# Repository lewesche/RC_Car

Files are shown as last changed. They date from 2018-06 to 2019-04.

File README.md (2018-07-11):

# RC_Car

Building an Arduino powered RC car. Hoping to eventually turn this into more than an RC car at some point (vision? autonomy? camera with gimbal?). Mostly just trying to keep track of files for myself as of now, but feel free to use any of this. CAD is done in Solidworks/Onshape (free option) and most parts are designed to be 3D printed. Code could be a useful reference for PWM control/radio communication.

## Hardware
##### Arduino Uno (2) 
https://store.arduino.cc/usa/arduino-uno-rev3
Note: One Uno used to send the joystick signal, the other is used integrated into the car to receive the signal. A Mini could be used instead to send the signal. 
##### TB6612 H-Bridge Controller (1)
https://learn.adafruit.com/adafruit-tb6612-h-bridge-dc-stepper-motor-driver-breakout?view=all
Note: One channel is set to output a constant ~5.5v for the servos, the other channel is activley controlled to run the driveshaft.
##### NRF24L01 Radio (2)
https://www.amazon.com/MakerFocus-NRF24L01-Transceiver-Antistatic-Compatible/dp/B01IK78PQA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
##### NRF24L01 5v Adapter Socket (1)
https://www.amazon.com/gp/product/B00NJCB7FS/ref=oh_aui_detailpage_o02_s00?ie=UTF8&psc=1
Note: Only one of these is used on the sender side. The idea is to hopefully imporve the range by working around some power issues associated with using the Uno's 3.3v onboard power. 
##### Joystick (1)
https://www.amazon.com/WGCD-Joystick-Breakout-Controller-Arduino/dp/B01N59MK0U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
Note: These joysticks aren't very sensitive. I'll probably look for better ones eventually.
##### 12V 200rpm DC motor (1)
https://www.amazon.com/Greartisan-Electric-Reduction-Eccentric-Diameter/dp/B072R5QSRG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
Note: Could use a higher RPM motor, this is just what I had.
##### 180 deg Servo (2)
https://www.amazon.com/Adafruit-Micro-Servo-Torque-ADA1143/dp/B01BMRDXK8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
##### Bevel Gears
https://www.amazon.com/gp/product/B004N62ZGE/ref=oh_aui_detailpage_o05_s00?ie=UTF8&psc=1

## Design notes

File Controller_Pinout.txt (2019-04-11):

Rover Arduino Pinout

3.3v - NRF
5v - Joystick
GND - NRF, Joystick

0 -
1 - 
2 - 
3 - 
4 - 
5 - 
6 - 
7 - NRF CE
8 - NRF CSN
9 - 
10 - 
11 - NRF MOS
12 - NRF MSC
13 - NRF SCK

A0 - VRY
A1 - VRX
A2 - 
A3 - 
A4 - 
A5 -

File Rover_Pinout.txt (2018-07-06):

Rover Arduino Pinout

3.3v - NRF
5v - Tb6612
GND - NRF, TB6612
vin - Vm

0 -
1 - 
2 - Servo1, Servo2
3 - AIN1
4 - AIN2
5 - PWMA
6 - IN1B
7 - NRF CE
8 - NRF CSN
9 - BIN2
10 - PWMB
11 - NRF MOS
12 - NRF MSC
13 - NRF SCK

A0 - Voltage/3 read
A1 - 
A2 - 
A3 - 
A4 - 
A5 - Low voltage indicator LED

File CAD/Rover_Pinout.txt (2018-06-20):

Rover Arduino Pinout

3.3v - NRF
5v - Servos
GND - NRF, Servos, DRV
vin - DRV vm

1 - 
2 - Servo1
3 - Servo2
4 - 
5 - DRV IN1
6 - DRV IN2
7 - NRF CE
8 - 
9 - 
10 - NRF CSN 
11 - NRF MOS
12 - NRF MSC
13 - NRF SCK

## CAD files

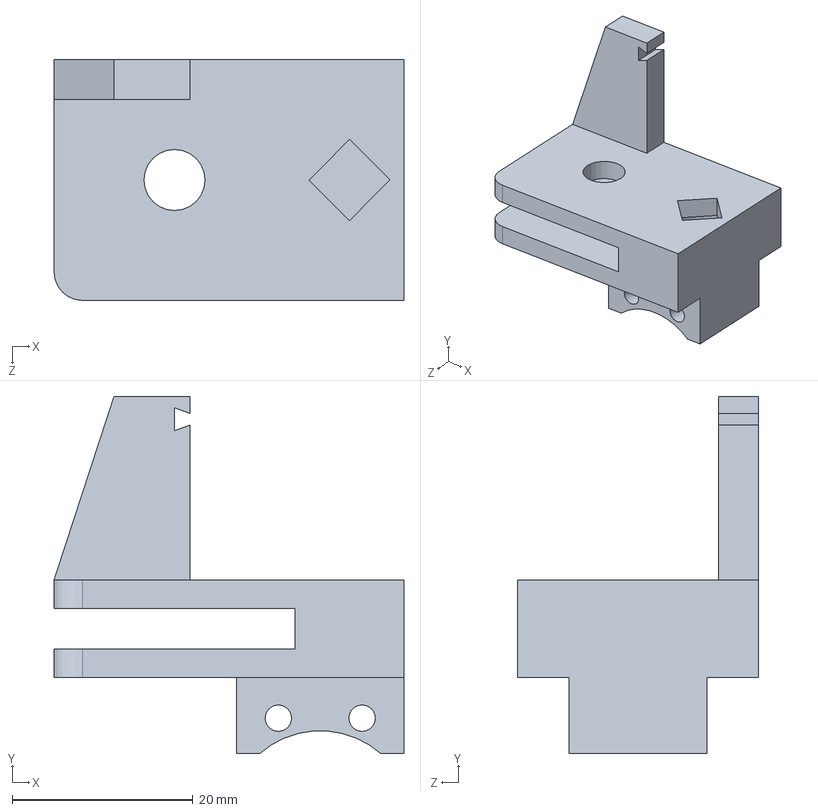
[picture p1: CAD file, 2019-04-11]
CAD/Solidworks Parts/Steering_Mount_Left.SLDPRT
38.7 x 39.6 x 26.7 mm

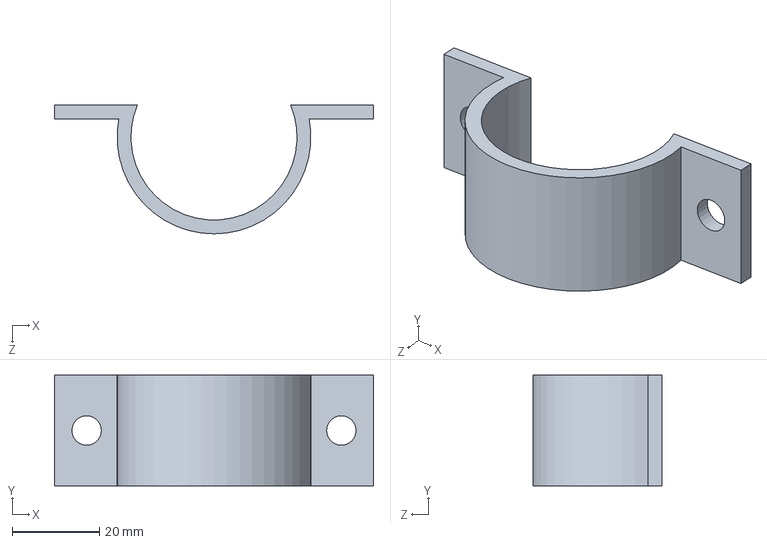
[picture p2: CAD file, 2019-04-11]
CAD/Solidworks Parts/Motor_Mount_Bottom.SLDPRT
73.2 x 25.4 x 29.5 mm

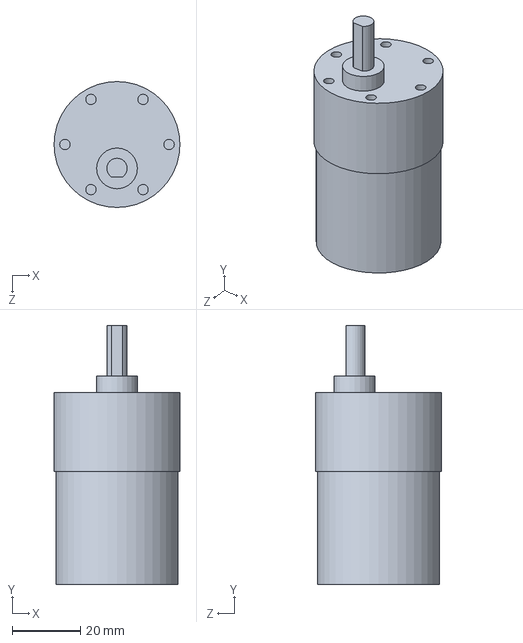
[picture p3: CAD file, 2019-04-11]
CAD/Solidworks Parts/Motor.SLDPRT
36.8 x 75.8 x 36.8 mm

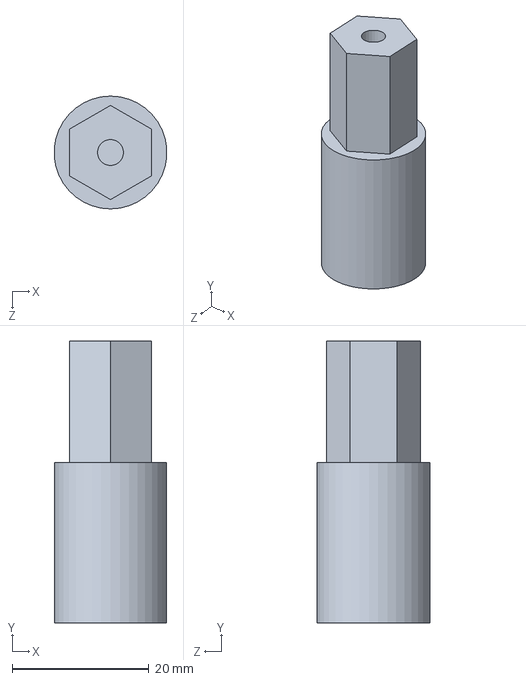
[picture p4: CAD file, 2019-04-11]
CAD/Solidworks Parts/Front_Bearing.SLDPRT
16.5 x 41.3 x 16.5 mm

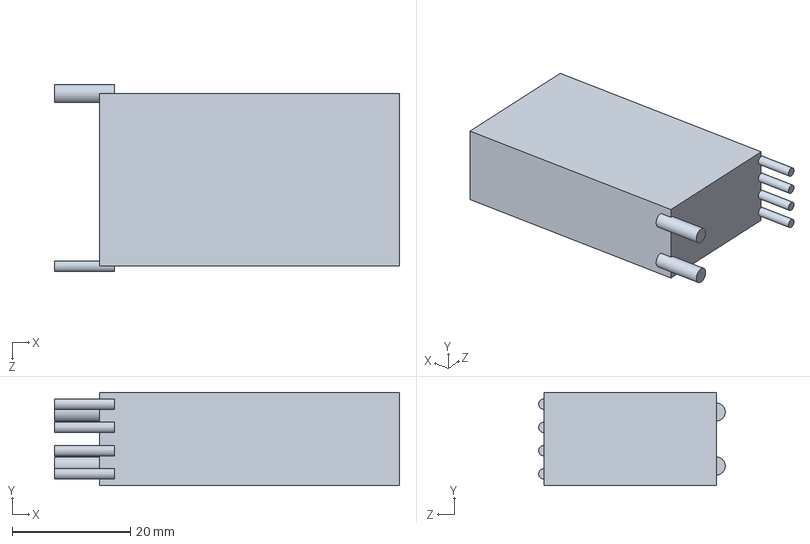
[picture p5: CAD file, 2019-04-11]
CAD/Solidworks Parts/LiPo_450.SLDPRT
58.4 x 15.7 x 31.6 mm

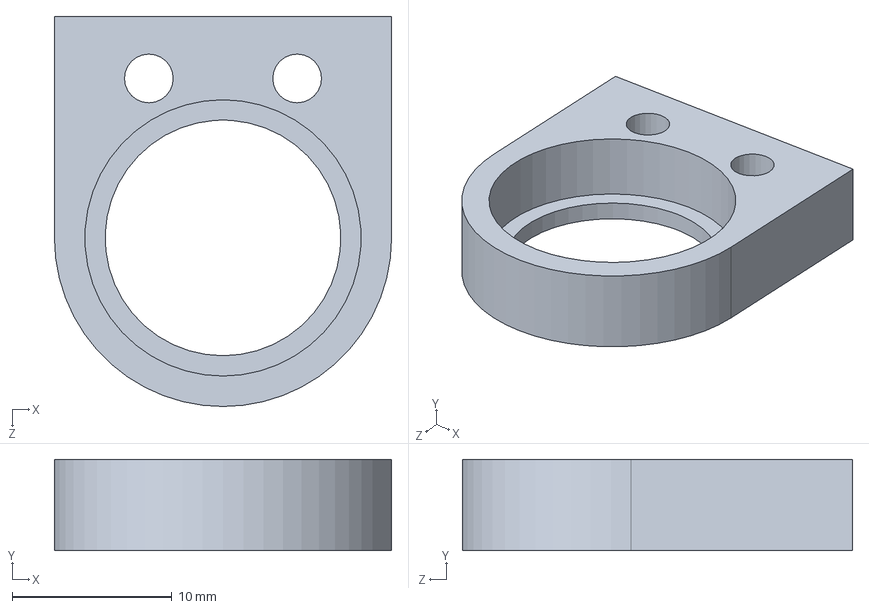
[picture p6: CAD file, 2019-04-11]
CAD/Solidworks Parts/Front_Mount.SLDPRT
21.1 x 5.72 x 24.4 mm

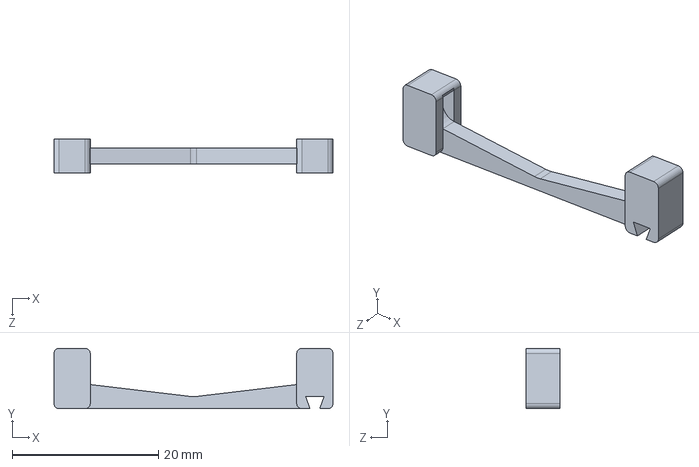
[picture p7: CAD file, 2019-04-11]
CAD/Solidworks Parts/Servo_Attachment.SLDPRT
38.1 x 8.26 x 4.70 mm

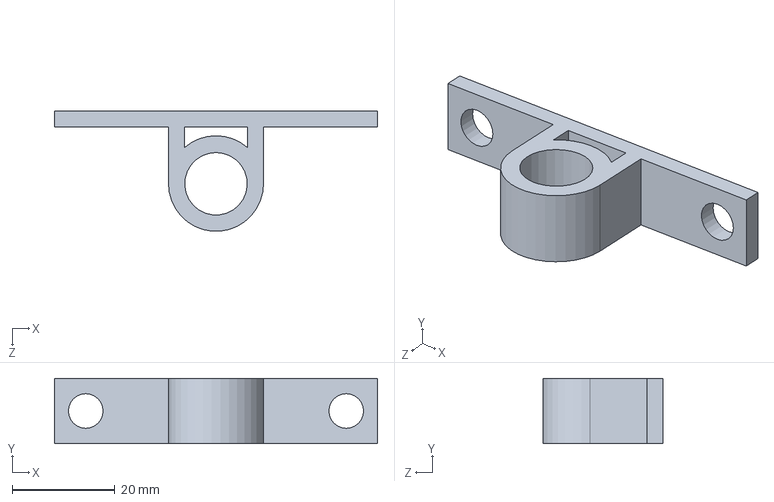
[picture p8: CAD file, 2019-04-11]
CAD/Solidworks Parts/Driveshaft_Mount.SLDPRT
63.0 x 12.7 x 23.5 mm

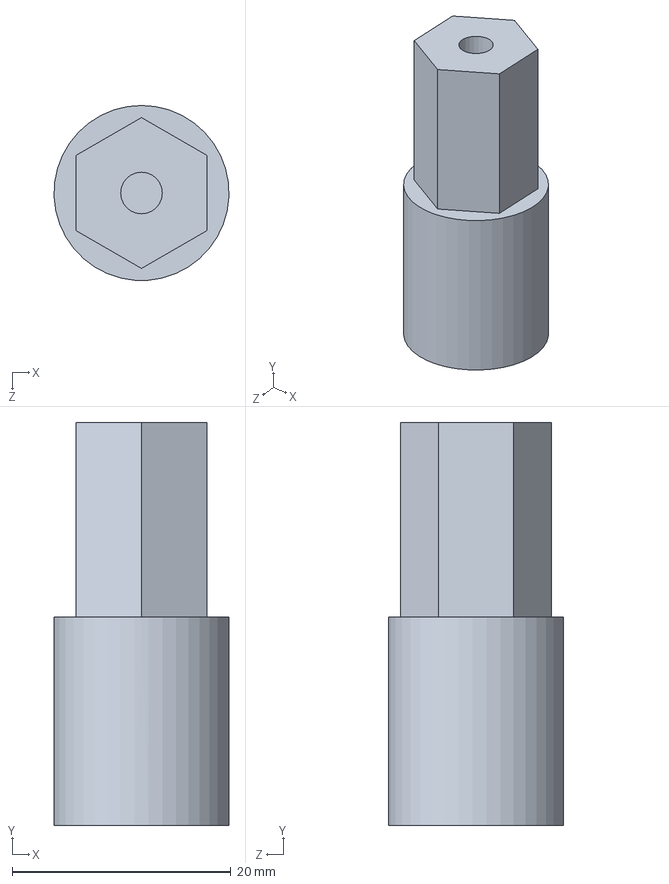
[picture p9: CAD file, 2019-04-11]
CAD/Solidworks Parts/Rear_Axle_Rod.SLDPRT
16.0 x 36.8 x 16.0 mm

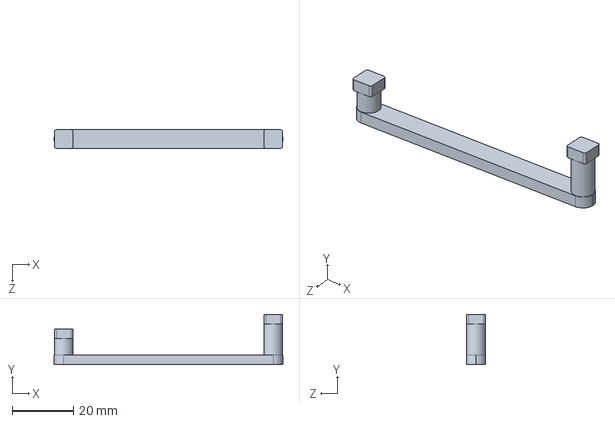
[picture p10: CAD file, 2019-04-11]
CAD/Solidworks Parts/Steering_linkage.SLDPRT
74.9 x 16.5 x 6.35 mm

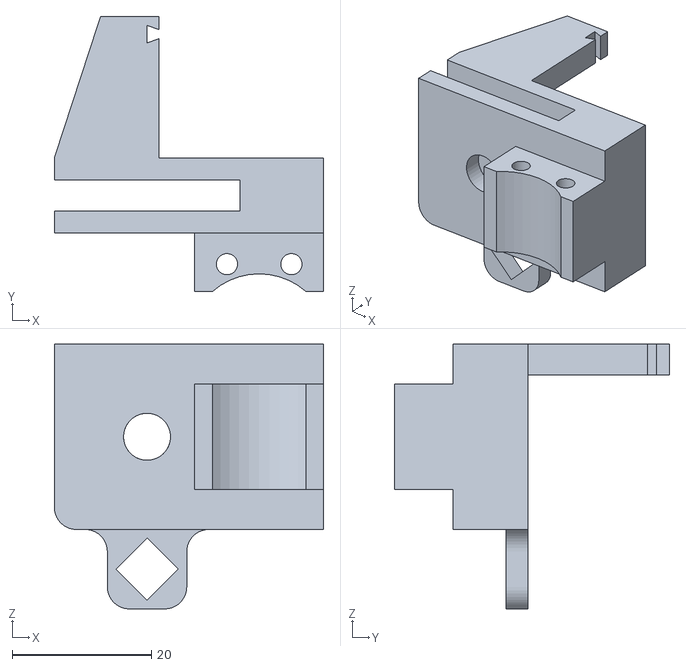
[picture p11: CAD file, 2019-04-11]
CAD/Solidworks Parts/Steering_Mount_Right_test2.STL
38.7 x 39.6 x 38.1

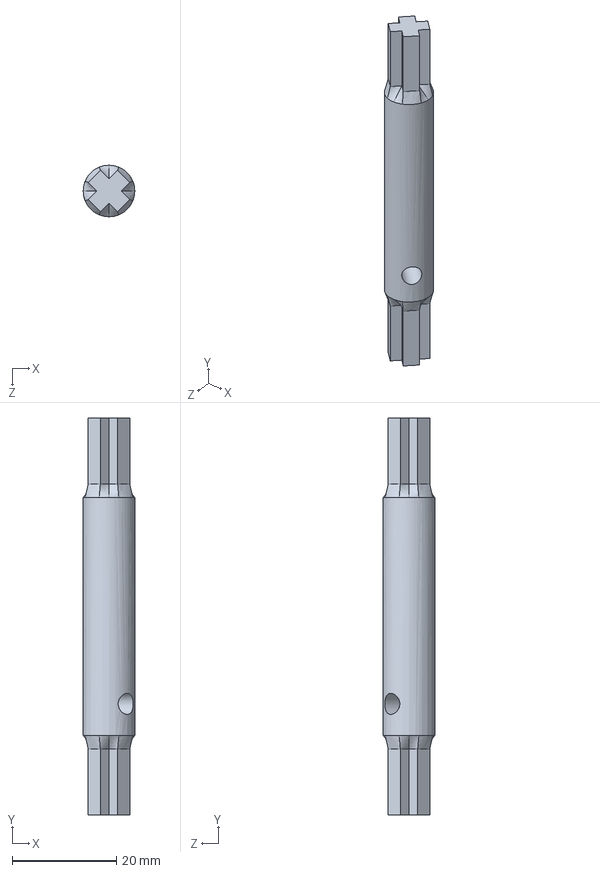
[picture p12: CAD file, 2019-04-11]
CAD/Solidworks Parts/Rear_Axle_cross.SLDPRT
9.91 x 76.2 x 9.91 mm

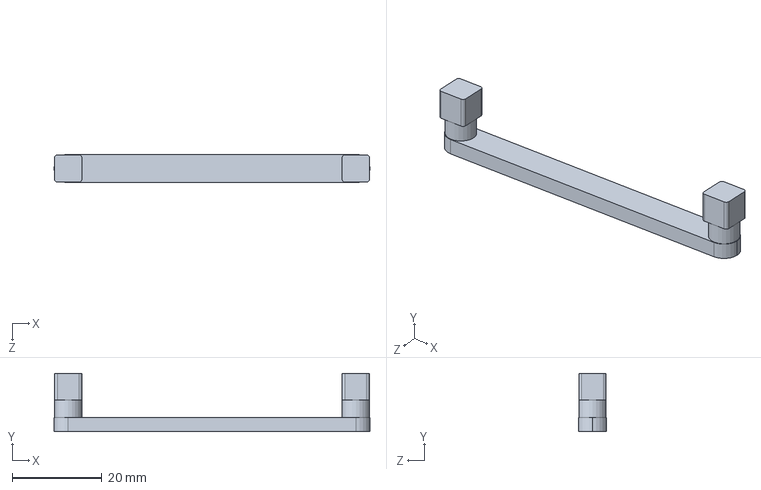
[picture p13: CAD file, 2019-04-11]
CAD/Solidworks Parts/Steering_Rack.SLDPRT
70.5 x 13.0 x 6.35 mm

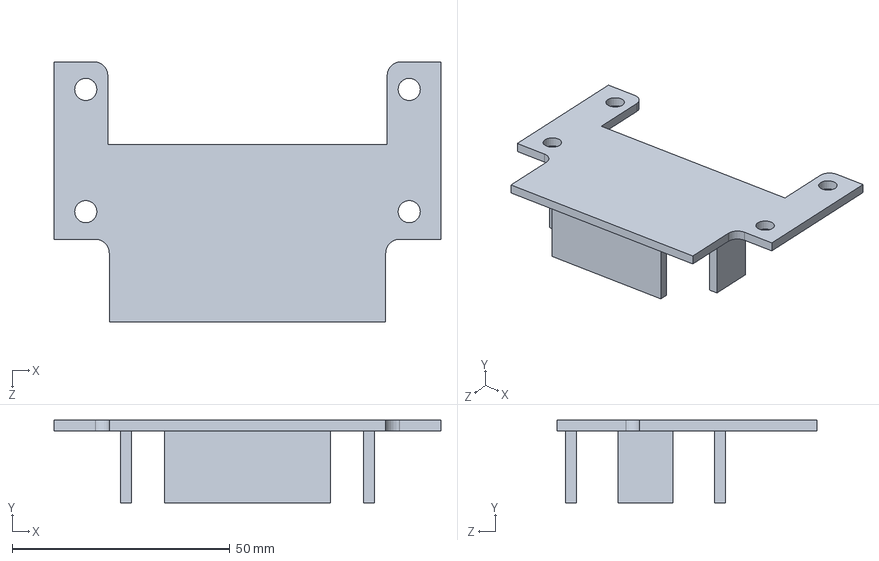
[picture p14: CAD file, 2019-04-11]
CAD/Solidworks Parts/LiPo_Mount.SLDPRT
88.9 x 19.1 x 59.8 mm

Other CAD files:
CAD/Solidworks Parts/Rear_Axle_Mount.SLDPRT
CAD/Solidworks Parts/MG90S_Servo.SLDPRT
CAD/Solidworks Parts/Steering_Mount.SLDPRT
CAD/Solidworks Parts/Arduino UNO.SLDPRT
CAD/Solidworks Parts/Bevel_Gear_2.SLDPRT
CAD/Solidworks Parts/Bevel_Gear_3.SLDPRT
CAD/Solidworks Parts/Driveshaft.SLDPRT
CAD/Solidworks Parts/Front_Wheel.SLDPRT
CAD/Solidworks Parts/Gear_Test_Fit.SLDPRT
CAD/Solidworks Parts/Motor_Mount_Top.SLDPRT
CAD/Solidworks Parts/Motor_Rod.SLDPRT
CAD/Solidworks Parts/Plate.SLDPRT
CAD/Solidworks Parts/RC_Plate.DXF
CAD/Solidworks Parts/Rear_Wheel.SLDPRT
CAD/Solidworks Parts/Servo_Attachment_2.SLDPRT
CAD/Solidworks Parts/Steering_Mount_Left.STL
CAD/Solidworks Parts/Steering_Mount_Right.SLDPRT
CAD/Solidworks Parts/Test_Fit_4.SLDPRT

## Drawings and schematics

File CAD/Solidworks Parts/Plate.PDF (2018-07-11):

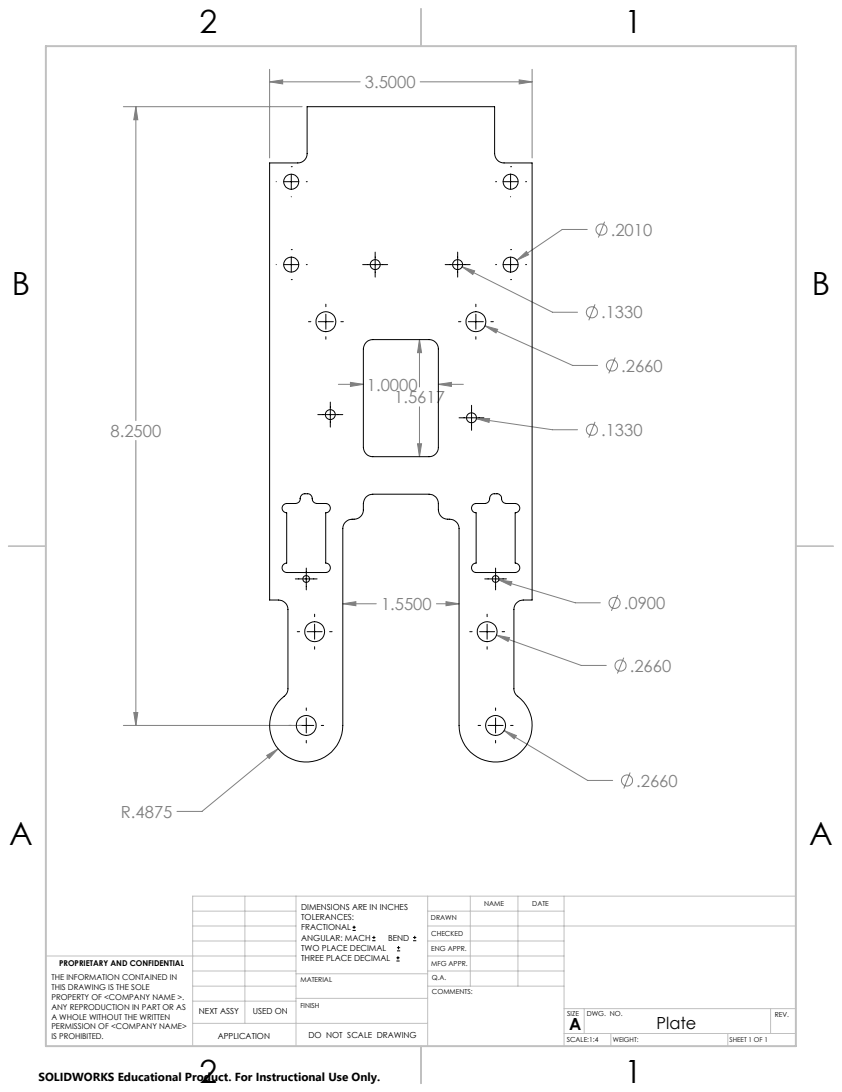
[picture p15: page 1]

TOLERANCES: FRACTIONAL ANGULAR: MACH BEND TWO PLACE DECIMAL THREE PLACE DECIMAL | | NAME | DATE DIMENSIONS ARE IN INCHES

DRAWN
CHECKED
ENG APPR.

PROPRIETARY AND CONFIDENTIAL THE INFORMATION CONTAINED IN THIS DRAWING IS THE SOLE PROPERTY OF <COMPANY NAME >. ANY REPRODUCTION IN PART OR AS A WHOLE WITHOUT THE WRITTEN PERMISSION OF <COMPANY NAME> IS PROHIBITED. | | | MFG APPR.

MATERIAL | Q.A.

NEXT ASSY | USED ON | FINISH

SIZE A | DWG. NO. Plate | REV.

APPLICATION | | DO NOT SCALE DRAWING

SCALE:1:4 | WEIGHT: | SHEET 1 OF 1

SOLIDWORKS Educational Product. For Instructional Use Only.

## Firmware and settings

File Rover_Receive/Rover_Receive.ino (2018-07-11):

#include <SPI.h>
//#include "RF24.h"
//#include <nRF24L01.h>
#include <RF24.h>
#include <Servo.h>



RF24 radio(7,8);             // CE, CNS
byte address[6] = "10000";    // radio adress
int pckg[3];                  // variable to read radio package data

Servo servo;                 // create servo object to control a servo

int Xval;                     // variable to read the value from the analog pin
int Yval;                     // variable to read the value from the analog pin

int M_IN1 = 9;               // directional motor output
int M_IN2 = 6;              // directional motor output
int M_PWM = 10;                // Motor PWM

int S_IN1 = 3;                // Servo directional input
int S_IN2 = 4;                // Servo directional input
int S_PWM = 5;                // Servo PWM

int battPin = A0;             // analog pin used to connect to battery (voltage divider)
int battRead;                 // variable to read the value from battPin
float battVoltage;            // battery voltage
//int ledPin = A5;               // pin that sends voltage to battery indicating LED


void setup() {
  Serial.begin(115200);     
  radio.begin();            
  radio.openReadingPipe(1, address);
  radio.setPALevel(RF24_PA_LOW);
  radio.setDataRate(RF24_250KBPS);
  radio.startListening();
  
  servo.attach(2);  // attaches the servo on pin 2 to the servo object

  pinMode(M_IN1, OUTPUT);
  pinMode(M_IN2, OUTPUT);
  pinMode(M_PWM, OUTPUT);

  pinMode(S_IN1, OUTPUT);
  pinMode(S_IN2, OUTPUT);
  pinMode(S_PWM, OUTPUT);

  digitalWrite(S_IN1, HIGH);
  digitalWrite(S_IN2, LOW);
  analogWrite(S_PWM, 107);
    
  pinMode(battPin, INPUT);
  //pinMode(ledPin, OUTPUT);
}

void loop() {
  //battRead = analogRead(battPin);
  //battVoltage = (5.*2.47/1023.)*(float)battRead;  //5 nominal input voltage, voltage divider gain 3
  //if (battVoltage < 10.5){
  //  digitalWrite(ledPin, LOW);
  //} else {
  //  digitalWrite(ledPin, LOW);
  //}
  
  if (radio.available()) {
    radio.read(&pckg, sizeof(pckg));
    
    Xval=pckg[0];
    Yval=pckg[1];

    servo.write(Yval);

    if (Xval > 0){
      digitalWrite(M_IN1, LOW);
      digitalWrite(M_IN2, HIGH);
      analogWrite(M_PWM, Xval);   
    }
  
    if (Xval < 0){
      digitalWrite(M_IN1, HIGH);
      digitalWrite(M_IN2, LOW);
      analogWrite(M_PWM, abs(Xval));
    }
  
    Serial.println(battVoltage);
    Serial.println(Xval);
    Serial.println(Yval);
  } //else {
    //Serial.println("Can't Find Radio");
  //}
  delay(10);
}

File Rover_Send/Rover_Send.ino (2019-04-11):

#include <SPI.h>
//#include "RF24.h" 
//#include <nRF24L01.h>
#include <RF24.h>
//#include <Servo.h>

RF24 radio(7, 8); // CE, CNS
byte address[6] = "10000";

int X = A1;  // analog pin used to connect the X potentiometer
int Xval;    // variable to read the value from the analog pin
int Y = A0;  // analog pin used to connect the Y potentiometer
int Yval;   // variable to read the value from the analog pin


const int SW = 4;       // digital pin used to read switch value
int SWval;  // variable to read the value from the switch pin

void setup() {
  Serial.begin(115200);
  radio.begin();
  radio.openWritingPipe(address);
  radio.setPALevel(RF24_PA_HIGH);
  radio.setDataRate(RF24_250KBPS);
  radio.stopListening();
  
  pinMode(SW, INPUT);
  digitalWrite(SW, HIGH);
}

void loop() {
  Yval = analogRead(Y);         
  Yval = map(Yval, 0, 1023, 115, 65);  
  Xval = analogRead(X);           
  Xval = map(Xval, 0, 1023, -255, 255);      

//  if (Yval > 100 && Xval > 180){
//    Xval = 180;
//  } else if (Yval > 100 && Xval < -180){
//    Xval = -180;
//  } else if (Yval < 80 && Xval > 180){
//    Xval = 180;
//  } else if (Yval < 80 && Xval < -180){
//    Xval = -180;
//  }
    
  int pckg[] = {Xval, Yval};
  radio.write(&pckg, sizeof(pckg));
  delay(10);
 
  Serial.println(pckg[0]);
  Serial.println(pckg[1]);
  
  
}

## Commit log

2018-06-22 Cad updates
    [Bevel_Gear_2.SLDPRT, Buggy.SLDASM, Driveshaft.SLDPRT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]
2018-06-25 Updated servo parameters, added LiPo voltage monitoring
    [Arduino UNO.SLDPRT, Bevel_Gear_2.SLDPRT, Buggy.SLDASM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]
2018-06-26 Got the LiPo voltage monitoring working
    [Front_Wheel.STL, Plate.STL, Rear_Wheel.STL]
2018-07-11 Updated CAD, electrical schematic coming soon
    [Arduino UNO.SLDPRT, Bevel_Gear_3.SLDPRT, Buggy.SLDASM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]
2019-04-11 Re-designed steering rack
    Designed a more robust system of 3D printed steering linkages. Works great.
    [40pin.SLDPRT, AdafruitStepperHat.SLDPRT, Arduino UNO.SLDPRT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]
2019-04-11 Added new PCB design
    [40pin.SLDPRT, AdafruitStepperHat.SLDPRT, Arduino UNO.SLDPRT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]
